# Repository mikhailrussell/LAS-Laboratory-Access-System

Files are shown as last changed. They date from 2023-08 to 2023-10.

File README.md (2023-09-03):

# LAS-Laboratory-Access-System-
Current PCB Version: **LAS_V2**
You can find the most recent version of the PCB under /PCB

# User Requirements
|Number/Label	|Requirement|
|---|---|
|UR-1	| Allow clients to book particular sessions (time and date). |
|UR-2|	Allow clients to view what the status of laboratory.
|UR-3|	Integrate access control with the current student card for identification.
|UR-4|	Provide access to clients who have been allocated the correct session.
|UR-5|	The status of benches must be physically displayed on the bench.
|UR-6|	The system must be easily scalable.
|UR-7|	The system must be cheap.

# Hardware Functional Requirements

|Number/label	|Requirements	|Acceptance Test Criteria|
|---|---|---|
|FR-1	|Retrieve student's IDs from 125KHz RFID student cards.	|
|FR-2	|Connect to network wirelessly.	|
|FR-3	|Each bench must have LEDs to indicate whether the bench is available, booked or in use.|	
|FR-4	|Each node must be able to activate a 220V relay.	|
|FR-5	|Operate off 12V	|
|FR-6	|Cheap and easily scalable	|

# Software Functional Requirements

|Number/label	|Requirements	|Acceptance Test Criteria|
|---|---|---|
|FR-6|	Site accessible via Wi-Fi (website accessible)	|
FR-7|	Free	|
FR-8|	Client able to book time and date	|
FR-9	|Current lab status is displayed (eg. Current tables free)	|

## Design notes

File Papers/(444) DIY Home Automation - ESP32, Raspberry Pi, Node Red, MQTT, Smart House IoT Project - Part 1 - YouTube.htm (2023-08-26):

•

NaN / NaN

Back

(https://www.youtube.com/) ZA

Skip navigation

Search

Search

Search with your voice

9+

Notifications

Avatar image

(https://www.youtube.com/) ZA

DIY Home Automation - ESP32, Raspberry Pi, Node Red, MQTT, Smart House || IoT Project - Part 1

Watch later

Share

Copy link

Info

Shopping

Tap to unmute

If playback doesn't begin shortly, try restarting your device.

5 seconds

More from Boris Dusnoki

Up next

Live

Upcoming

CancelPlay Now

Boris Dusnoki (https://www.youtube.com/channel/UCgOEgQpu1thY7D-GzO5vdeQ)

Subscribe

Subscribed

Web developer, electronics hobbyist, guitar enthusiast and traveler.

DIY Arduino Ambilight RGB WS2812b Full Build & How-To (https://www.youtube.com/watch?v=juC-3imLoTQ)

8:15

You're signed out

Videos you watch may be added to the TV's watch history and influence TV recommendations. To avoid this, cancel and sign in to YouTube on your computer.

CancelConfirm

Switch camera

Share

Include playlist

An error occurred while retrieving sharing information. Please try again later.

7:16

(https://www.youtube.com/watch?v=_DO2wHI6JWQ)

7:47 / 12:24•Watch full videoLive

•

•

Scroll for details

# DIY Home Automation - ESP32, Raspberry Pi, Node Red, MQTT, Smart House || IoT Project - Part 1

 (https://www.youtube.com/@dusnoki)

Boris Dusnoki (https://www.youtube.com/@dusnoki)

Boris Dusnoki

4.06K subscribers

Subscribe

<__slot-el>

Subscribed

1.3K

I like this

I dislike this

Share

Share

Download

Download

Clip

Clip

Save

Save

61K views 4 years ago Raspberry Pi (https://www.youtube.com/playlist?list=PLuWKCYWPj895uvLiwB4n7BlYf247BNhpS)

Show less

JLCPCB Prototype for $2(Any Color): https://jlcpcb.com (https://www.youtube.com/redirect?event=video_description&q=https%3A%2F%2Fjlcpcb.com%2F&v=kRvNlSJs0Hg) !!!! IMPORTANT !!!! Please use version 1.0.0 of the ESP32 board from the board manager. …...more

...more

Show less

61,500 views • Nov 28, 2018 • Raspberry Pi

Raspberry Pi (https://www.youtube.com/playlist?list=PLuWKCYWPj895uvLiwB4n7BlYf247BNhpS)

# DIY Home Automation - ESP32, Raspberry Pi, Node Red, MQTT, Smart House || IoT Project - Part 1

61,500 views61K views

Nov 28, 2018

1.3K

I like this

I dislike this

Share

Share

Download

Download

Clip

Clip

Save

Save

(https://www.youtube.com/@dusnoki)

Boris Dusnoki (https://www.youtube.com/@dusnoki)

Boris Dusnoki

4.06K subscribers

Subscribe

<__slot-el>

Subscribed

JLCPCB Prototype for $2(Any Color): https://jlcpcb.com (https://www.youtube.com/redirect?event=video_description&q=https%3A%2F%2Fjlcpcb.com%2F&v=kRvNlSJs0Hg) !!!! IMPORTANT !!!! Please use version 1.0.0 of the ESP32 board from the board manager. Check out my first attempt at a DIY Home Automation project. With this small box I could control my tv, led strip, sound system and lights. It would also monitor the inside humidity and temperature as well as get real time data from an external API for the outside humidity and temperature and display them nicely in a graph. I even save all these values to a local database and display those values in a chart based on the date I choose. Part 2: Code and Node Red Explanation - • DIY Home Automati... (https://www.youtube.com/watch?v=menuVmKz-mc&t=0s) ESP32: http://y.sudokin.com/esp32 (https://www.youtube.com/redirect?event=video_description&q=http%3A%2F%2Fy.sudokin.com%2Fesp32&v=kRvNlSJs0Hg) - AliExpress http://y.sudokin.com/besp32 (https://www.youtube.com/redirect?event=video_description&q=http%3A%2F%2Fy.sudokin.com%2Fbesp32&v=kRvNlSJs0Hg) - Banggood http://y.sudokin.com/auesp32 (https://www.youtube.com/redirect?event=video_description&q=http%3A%2F%2Fy.sudokin.com%2Fauesp32&v=kRvNlSJs0Hg) - Amazon US http://y.sudokin.com/akesp32 (https://www.youtube.com/redirect?event=video_description&q=http%3A%2F%2Fy.sudokin.com%2Fakesp32&v=kRvNlSJs0Hg) - Amazon UK http://y.sudokin.com/adesp32 (https://www.youtube.com/redirect?event=video_description&q=http%3A%2F%2Fy.sudokin.com%2Fadesp32&v=kRvNlSJs0Hg) - Amazon DE Raspberry Pi Zero W: http://y.sudokin.com/rpzw (https://www.youtube.com/redirect?event=video_description&q=http%3A%2F%2Fy.sudokin.com%2Frpzw&v=kRvNlSJs0Hg) - AliExpress http://y.sudokin.com/brpzw (https://www.youtube.com/redirect?event=video_description&q=http%3A%2F%2Fy.sudokin.com%2Fbrpzw&v=kRvNlSJs0Hg) - Banggood http://y.sudokin.com/aurpzw (https://www.youtube.com/redirect?event=video_description&q=http%3A%2F%2Fy.sudokin.com%2Faurpzw&v=kRvNlSJs0Hg) - Amazon US http://y.sudokin.com/akrpzw (https://www.youtube.com/redirect?event=video_description&q=http%3A%2F%2Fy.sudokin.com%2Fakrpzw&v=kRvNlSJs0Hg) - Amazon UK http://y.sudokin.com/adrpzw (https://www.youtube.com/redirect?event=video_description&q=http%3A%2F%2Fy.sudokin.com%2Fadrpzw&v=kRvNlSJs0Hg) - Amazon DE HTU21D Temperature and Humidity Sensor: http://y.sudokin.com/htu21d (https://www.youtube.com/redirect?event=video_description&q=http%3A%2F%2Fy.sudokin.com%2Fhtu21d&v=kRvNlSJs0Hg) - AliExpress http://y.sudokin.com/bhtu21d (https://www.youtube.com/redirect?event=video_description&q=http%3A%2F%2Fy.sudokin.com%2Fbhtu21d&v=kRvNlSJs0Hg) - Banggood http://y.sudokin.com/auhtu21d (https://www.youtube.com/redirect?event=video_description&q=http%3A%2F%2Fy.sudokin.com%2Fauhtu21d&v=kRvNlSJs0Hg) - Amazon US http://y.sudokin.com/akhtu21d (https://www.youtube.com/redirect?event=video_description&q=http%3A%2F%2Fy.sudokin.com%2Fakhtu21d&v=kRvNlSJs0Hg) - Amazon UK http://y.sudokin.com/adhtu21d (https://www.youtube.com/redirect?event=video_description&q=http%3A%2F%2Fy.sudokin.com%2Fadhtu21d&v=kRvNlSJs0Hg) - Amazon DE 1838 IR Receiver: http://y.sudokin.com/1838 (https://www.youtube.com/redirect?event=video_description&q=http%3A%2F%2Fy.sudokin.com%2F1838&v=kRvNlSJs0Hg) - AliExpress http://y.sudokin.com/b1838 (https://www.youtube.com/redirect?event=video_description&q=http%3A%2F%2Fy.sudokin.com%2Fb1838&v=kRvNlSJs0Hg) - Banggood http://y.sudokin.com/au1838 (https://www.youtube.com/redirect?event=video_description&q=http%3A%2F%2Fy.sudokin.com%2Fau1838&v=kRvNlSJs0Hg) - Amazon US http://y.sudokin.com/ak1838 (https://www.youtube.com/redirect?event=video_description&q=http%3A%2F%2Fy.sudokin.com%2Fak1838&v=kRvNlSJs0Hg) - Amazon UK http://y.sudokin.com/ad1838 (https://www.youtube.com/redirect?event=video_description&q=http%3A%2F%2Fy.sudokin.com%2Fad1838&v=kRvNlSJs0Hg) - Amazon DE Female Pin Headers: http://y.sudokin.com/ph (https://www.youtube.com/redirect?event=video_description&q=http%3A%2F%2Fy.sudokin.com%2Fph&v=kRvNlSJs0Hg) - Aliexpress http://y.sudokin.com/auph (https://www.youtube.com/redirect?event=video_description&q=http%3A%2F%2Fy.sudokin.com%2Fauph&v=kRvNlSJs0Hg) - Amazon US http://y.sudokin.com/akph (https://www.youtube.com/redirect?event=video_description&q=http%3A%2F%2Fy.sudokin.com%2Fakph&v=kRvNlSJs0Hg) - Amazon UK http://y.sudokin.com/adph (https://www.youtube.com/redirect?event=video_description&q=http%3A%2F%2Fy.sudokin.com%2Fadph&v=kRvNlSJs0Hg) - Amazon DE Soldering station: http://y.sudokin.com/auss (https://www.youtube.com/redirect?event=video_description&q=http%3A%2F%2Fy.sudokin.com%2Fauss&v=kRvNlSJs0Hg) - Amazon US http://y.sudokin.com/akss (https://www.youtube.com/redirect?event=video_description&q=http%3A%2F%2Fy.sudokin.com%2Fakss&v=kRvNlSJs0Hg) - Amazon UK http://y.sudokin.com/adss (https://www.youtube.com/redirect?event=video_description&q=http%3A%2F%2Fy.sudokin.com%2Fadss&v=kRvNlSJs0Hg) - Amazon DE Software Links: Raspberry Pi Image - http://y.sudokin.com/dietpi (https://www.youtube.com/redirect?event=video_description&q=http%3A%2F%2Fy.sudokin.com%2Fdietpi&v=kRvNlSJs0Hg) EasyEDA Project - http://y.sudokin.com/hauea (https://www.youtube.com/redirect?event=video_description&q=http%3A%2F%2Fy.sudokin.com%2Fhauea&v=kRvNlSJs0Hg) Gerber Files - http://y.sudokin.com/hauger (https://www.youtube.com/redirect?event=video_description&q=http%3A%2F%2Fy.sudokin.com%2Fhauger&v=kRvNlSJs0Hg) Github Project Repository - http://y.sudokin.com/haugh (https://www.youtube.com/redirect?event=video_description&q=http%3A%2F%2Fy.sudokin.com%2Fhaugh&v=kRvNlSJs0Hg) Arduino ESP32 Github Repository - http://y.sudokin.com/aresp32gh (https://www.youtube.com/redirect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) Arduino IDE - https://www.arduino.cc/en/Main/Software (https://www.youtube.com/redirect?event=video_description&v=kRvNlSJs0Hg) Etcher - https://www.balena.io/etcher/ (https://www.youtube.com/redirect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) Node Red Admin address: ip-address-to-raspberry-pi:1880 username: admin password: password Node Red UI address: ip-address-to-raspberry-pi:1880/ui username: user password: password Raspberry pi user: pi Raspberry pi password: password →Support the channel via Patreon, Paypal, Bitcoin, Etherium or by visiting affiliate links https://sudokin.com/donate (https://www.youtube.com/redirect?event=video_description&q=https%3A%2F%2Fsudokin.com%2Fdonate&v=kRvNlSJs0Hg) Follow me on LBRY: https://y.sudokin.com/lbry (https://www.youtube.com/redirect?event=video_description&q=https%3A%2F%2Fy.sudokin.com%2Flbry&v=kRvNlSJs0Hg) Follow me on Twitter & Instagram and my blog: https://twitter.com/dusnoki (https://www.youtube.com/redirect?event=video_description&q=https%3A%2F%2Ftwitter.com%2Fdusnoki&v=kRvNlSJs0Hg) https://instagram.com/dusnoki (https://www.youtube.com/redirect?event=video_description&q=https%3A%2F%2Finstagram.com%2Fdusnoki&v=kRvNlSJs0Hg) https://sudokin.com (https://www.youtube.com/redirect?event=video_description&q=https%3A%2F%2Fsudokin.com%2F&v=kRvNlSJs0Hg) Or hop on to my Discord channel: https://discord.gg/Aef4VRc (https://www.youtube.com/redirect?event=video_description&q=https%3A%2F%2Fdiscord.gg%2FAef4VRc&v=kRvNlSJs0Hg) Thanks for watching, and I hope you learned something ;)

## Key moments

## View all

#### communicate using the mqtt protocol (https://www.youtube.com/watch?v=kRvNlSJs0Hg&t=80s)

#### communicate using the mqtt protocol

1:20

1:20

#### send infrared controls to multiple devices (https://www.youtube.com/watch?v=kRvNlSJs0Hg&t=333s)

#### send infrared controls to multiple devices

5:33

5:33

#### insert your sd card-raspberry pi (https://www.youtube.com/watch?v=kRvNlSJs0Hg&t=437s)

#### insert your sd card-raspberry pi

7:17

7:17

#### use the arduino ide for uploading (https://www.youtube.com/watch?v=kRvNlSJs0Hg&t=450s)

#### use the arduino ide for uploading

7:30

7:30

#### put all the necessary components of the breadboard (https://www.youtube.com/watch?v=kRvNlSJs0Hg&t=528s)

#### put all the necessary components of the breadboard

8:48

8:48

#### create a custom pcb for this project (https://www.youtube.com/watch?v=kRvNlSJs0Hg&t=542s)

#### create a custom pcb for this project

9:02

9:02

#### solder the esp 32 to the board (https://www.youtube.com/watch?v=kRvNlSJs0Hg&t=625s)

#### solder the esp 32 to the board

10:25

10:25

#### solder each wire in place to the board (https://www.youtube.com/watch?v=kRvNlSJs0Hg&t=655s)

#### solder each wire in place to the board

10:55

10:55

### Featured playlist

5 videos (https://www.youtube.com/playlist?list=PLuWKCYWPj895uvLiwB4n7BlYf247BNhpS)

Raspberry Pi

Boris Dusnoki

### Boris Dusnoki (https://www.youtube.com/@dusnoki)

4.06K subscribers

Videos (https://www.youtube.com/channel/UCgOEgQpu1thY7D-GzO5vdeQ/videos)

About (https://www.youtube.com/channel/UCgOEgQpu1thY7D-GzO5vdeQ/about)

39:33 (https://www.youtube.com/watch?v=menuVmKz-mc)

DIY Home Automation - Part 2 Code and Node Red Explanation | ESP32, Raspberry Pi, MQTT, Smart House (https://www.youtube.com/watch?v=menuVmKz-mc)

by Boris Dusnoki

10K views · 4 years ago

Show less ...more

## Key moments

#### communicate using the mqtt protocol (https://www.youtube.com/watch?v=kRvNlSJs0Hg&t=80s)

#### communicate using the mqtt protocol

1:20

1:20

#### send infrared controls to multiple devices (https://www.youtube.com/watch?v=kRvNlSJs0Hg&t=333s)

#### send infrared controls to multiple devices

5:33

5:33

#### insert your sd card-raspberry pi (https://www.youtube.com/watch?v=kRvNlSJs0Hg&t=437s)

#### insert your sd card-raspberry pi

7:17

7:17

#### use the arduino ide for uploading (https://www.youtube.com/watch?v=kRvNlSJs0Hg&t=450s)

#### use the arduino ide for uploading

7:30

7:30

#### put all the necessary components of the breadboard (https://www.youtube.com/watch?v=kRvNlSJs0Hg&t=528s)

#### put all the necessary components of the breadboard

8:48

8:48

#### create a custom pcb for this project (https://www.youtube.com/watch?v=kRvNlSJs0Hg&t=542s)

#### create a custom pcb for this project

9:02

9:02

#### solder the esp 32 to the board (https://www.youtube.com/watch?v=kRvNlSJs0Hg&t=625s)

#### solder the esp 32 to the board

10:25

10:25

#### solder each wire in place to the board (https://www.youtube.com/watch?v=kRvNlSJs0Hg&t=655s)

#### solder each wire in place to the board

10:55

10:55

#### added some heat shrink tubing to the wires of the infrared led (https://www.youtube.com/watch?v=kRvNlSJs0Hg&t=665s)

#### added some heat shrink tubing to the wires of the infrared led

11:05

11:05

Sync to video time

Sync to video time

## Create clip

Mikhail Russell

Public

Add a title (required)

0/140

–

30.0 seconds

Cancel

Share clip

Continue clipping after ad finishes

Can’t create clip while ad is playing

## Description

DIY Home Automation - ESP32, Raspberry Pi, Node Red, MQTT, Smart House || IoT Project - Part 1

(https://www.youtube.com/@dusnoki)

Boris Dusnoki

Boris Dusnoki

1.3K Likes

61,500 Views

2018 Nov 28

JLCPCB Prototype for $2(Any Color): https://jlcpcb.com (https://www.youtube.com/redirect?event=video_description&q=https%3A%2F%2Fjlcpcb.com%2F&v=kRvNlSJs0Hg) !!!! IMPORTANT !!!! Please use version 1.0.0 of the ESP32 board from the board manager. Check out my first attempt at a DIY Home Automation project. With this small box I could control my tv, led strip, sound system and lights. It would also monitor the inside humidity and temperature as well as get real time data from an external API for the outside humidity and temperature and display them nicely in a graph. I even save all these values to a local database and display those values in a chart based on the date I choose. Part 2: Code and Node Red Explanation - • DIY Home Automati... (https://www.youtube.com/watch?v=menuVmKz-mc&t=0s) ESP32: http://y.sudokin.com/esp32 (https://www.youtube.com/redirect?event=video_description&q=http%3A%2F%2Fy.sudokin.com%2Fesp32&v=kRvNlSJs0Hg) - AliExpress http://y.sudokin.com/besp32 (https://www.youtube.com/redirect?event=video_description&q=http%3A%2F%2Fy.sudokin.com%2Fbesp32&v=kRvNlSJs0Hg) - Banggood http://y.sudokin.com/auesp32 (https://www.youtube.com/redirect?event=video_description&q=http%3A%2F%2Fy.sudokin.com%2Fauesp32&v=kRvNlSJs0Hg) - Amazon US http://y.sudokin.com/akesp32 (https://www.youtube.com/redirect?event=video_description&q=http%3A%2F%2Fy.sudokin.com%2Fakesp32&v=kRvNlSJs0Hg) - Amazon UK http://y.sudokin.com/adesp32 (https://www.youtube.com/redirect?event=video_description&q=http%3A%2F%2Fy.sudokin.com%2Fadesp32&v=kRvNlSJs0Hg) - Amazon DE Raspberry Pi Zero W: http://y.sudokin.com/rpzw (https://www.youtube.com/redirect?event=video_description&q=http%3A%2F%2Fy.sudokin.com%2Frpzw&v=kRvNlSJs0Hg) - AliExpress http://y.sudokin.com/brpzw (https://www.youtube.com/redirect?event=video_description&q=http%3A%2F%2Fy.sudokin.com%2Fbrpzw&v=kRvNlSJs0Hg) - Banggood http://y.sudokin.com/aurpzw (https://www.youtube.com/redirect?event=video_description&q=http%3A%2F%2Fy.sudokin.com%2Faurpzw&v=kRvNlSJs0Hg) - Amazon US http://y.sudokin.com/akrpzw (https://www.youtube.com/redirect?event=video_description&q=http%3A%2F%2Fy.sudokin.com%2Fakrpzw&v=kRvNlSJs0Hg) - Amazon UK http://y.sudokin.com/adrpzw (https://www.youtube.com/redirect?event=video_description&q=http%3A%2F%2Fy.sudokin.com%2Fadrpzw&v=kRvNlSJs0Hg) - Amazon DE HTU21D Temperature and Humidity Sensor: http://y.sudokin.com/htu21d (https://www.youtube.com/redirect?event=video_description&q=http%3A%2F%2Fy.sudokin.com%2Fhtu21d&v=kRvNlSJs0Hg) - AliExpress http://y.sudokin.com/bhtu21d (https://www.youtube.com/redirect?event=video_description&q=http%3A%2F%2Fy.sudokin.com%2Fbhtu21d&v=kRvNlSJs0Hg) - Banggood http://y.sudokin.com/auhtu21d (https://www.youtube.com/redirect?event=video_description&q=http%3A%2F%2Fy.sudokin.com%2Fauhtu21d&v=kRvNlSJs0Hg) - Amazon US http://y.sudokin.com/akhtu21d (https://www.youtube.com/redirect?event=video_description&q=http%3A%2F%2Fy.sudokin.com%2Fakhtu21d&v=kRvNlSJs0Hg) - Amazon UK http://y.sudokin.com/adhtu21d (https://www.youtube.com/redirect?event=video_description&q=http%3A%2F%2Fy.sudokin.com%2Fadhtu21d&v=kRvNlSJs0Hg) - Amazon DE 1838 IR Receiver: http://y.sudokin.com/1838 (https://www.youtube.com/redirect?event=video_description&q=http%3A%2F%2Fy.sudokin.com%2F1838&v=kRvNlSJs0Hg) - AliExpress http://y.sudokin.com/b1838 (https://www.youtube.com/redirect?event=video_description&q=http%3A%2F%2Fy.sudokin.com%2Fb1838&v=kRvNlSJs0Hg) - Banggood http://y.sudokin.com/au1838 (https://www.youtube.com/redirect?event=video_description&q=http%3A%2F%2Fy.sudokin.com%2Fau1838&v=kRvNlSJs0Hg) - Amazon US http://y.sudokin.com/ak1838 (https://www.youtube.com/redirect?event=video_description&q=http%3A%2F%2Fy.sudokin.com%2Fak1838&v=kRvNlSJs0Hg) - Amazon UK http://y.sudokin.com/ad1838 (https://www.youtube.com/redirect?event=video_description&q=http%3A%2F%2Fy.sudokin.com%2Fad1838&v=kRvNlSJs0Hg) - Amazon DE Female Pin Headers: http://y.sudokin.com/ph (https://www.youtube.com/redirect?event=video_description&q=http%3A%2F%2Fy.sudokin.com%2Fph&v=kRvNlSJs0Hg) - Aliexpress http://y.sudokin.com/auph (https://www.youtube.com/redirect?event=video_description&q=http%3A%2F%2Fy.sudokin.com%2Fauph&v=kRvNlSJs0Hg) - Amazon US http://y.sudokin.com/akph (https://www.youtube.com/redirect?event=video_description&q=http%3A%2F%2Fy.sudokin.com%2Fakph&v=kRvNlSJs0Hg) - Amazon UK http://y.sudokin.com/adph (https://www.youtube.com/redirect?event=video_description&q=http%3A%2F%2Fy.sudokin.com%2Fadph&v=kRvNlSJs0Hg) - Amazon DE Soldering station: http://y.sudokin.com/auss (https://www.youtube.com/redirect?event=video_description&q=http%3A%2F%2Fy.sudokin.com%2Fauss&v=kRvNlSJs0Hg) - Amazon US http://y.sudokin.com/akss (https://www.youtube.com/redirect?event=video_description&q=http%3A%2F%2Fy.sudokin.com%2Fakss&v=kRvNlSJs0Hg) - Amazon UK http://y.sudokin.com/adss (https://www.youtube.com/redirect?event=video_description&q=http%3A%2F%2Fy.sudokin.com%2Fadss&v=kRvNlSJs0Hg) - Amazon DE Software Links: Raspberry Pi Image - http://y.sudokin.com/dietpi (https://www.youtube.com/redirect?event=video_description&q=http%3A%2F%2Fy.sudokin.com%2Fdietpi&v=kRvNlSJs0Hg) EasyEDA Project - http://y.sudokin.com/hauea (https://www.youtube.com/redirect?event=video_description&q=http%3A%2F%2Fy.sudokin.com%2Fhauea&v=kRvNlSJs0Hg) Gerber Files - http://y.sudokin.com/hauger (https://www.youtube.com/redirect?event=video_description&q=http%3A%2F%2Fy.sudokin.com%2Fhauger&v=kRvNlSJs0Hg) Github Project Repository - http://y.sudokin.com/haugh (https://www.youtube.com/redirect?event=video_description&q=http%3A%2F%2Fy.sudokin.com%2Fhaugh&v=kRvNlSJs0Hg) Arduino ESP32 Github Repository - http://y.sudokin.com/aresp32gh (https://www.youtube.com/redirect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) Arduino IDE - https://www.arduino.cc/en/Main/Software (https://www.youtube.com/redirect?event=video_description&v=kRvNlSJs0Hg) Etcher - https://www.balena.io/etcher/ (https://www.youtube.com/redirect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) Node Red Admin address: ip-address-to-raspberry-pi:1880 username: admin password: password Node Red UI address: ip-address-to-raspberry-pi:1880/ui username: user password: password Raspberry pi user: pi Raspberry pi password: password →Support the channel via Patreon, Paypal, Bitcoin, Etherium or by visiting affiliate links https://sudokin.com/donate (https://www.youtube.com/redirect?event=video_description&q=https%3A%2F%2Fsudokin.com%2Fdonate&v=kRvNlSJs0Hg) Follow me on LBRY: https://y.sudokin.com/lbry (https://www.youtube.com/redirect?event=video_description&q=https%3A%2F%2Fy.sudokin.com%2Flbry&v=kRvNlSJs0Hg) Follow me on Twitter & Instagram and my blog: https://twitter.com/dusnoki (https://www.youtube.com/redirect?event=video_description&q=https%3A%2F%2Ftwitter.com%2Fdusnoki&v=kRvNlSJs0Hg) https://instagram.com/dusnoki (https://www.youtube.com/redirect?event=video_description&q=https%3A%2F%2Finstagram.com%2Fdusnoki&v=kRvNlSJs0Hg) https://sudokin.com (https://www.youtube.com/redirect?event=video_description&q=https%3A%2F%2Fsudokin.com%2F&v=kRvNlSJs0Hg) Or hop on to my Discord channel: https://discord.gg/Aef4VRc (https://www.youtube.com/redirect?event=video_description&q=https%3A%2F%2Fdiscord.gg%2FAef4VRc&v=kRvNlSJs0Hg) Thanks for watching, and I hope you learned something ;)

Show less Show more

## Key moments

## View all

#### communicate using the mqtt protocol (https://www.youtube.com/watch?v=kRvNlSJs0Hg&t=80s)

#### communicate using the mqtt protocol

1:20

1:20

#### send infrared controls to multiple devices (https://www.youtube.com/watch?v=kRvNlSJs0Hg&t=333s)

#### send infrared controls to multiple devices

5:33

5:33

#### insert your sd card-raspberry pi (https://www.youtube.com/watch?v=kRvNlSJs0Hg&t=437s)

#### insert your sd card-raspberry pi

7:17

7:17

#### use the arduino ide for uploading (https://www.youtube.com/watch?v=kRvNlSJs0Hg&t=450s)

#### use the arduino ide for uploading

7:30

7:30

### Featured playlist

5 videos (https://www.youtube.com/playlist?list=PLuWKCYWPj895uvLiwB4n7BlYf247BNhpS)

Raspberry Pi

Boris Dusnoki

### Boris Dusnoki (https://www.youtube.com/@dusnoki)

4.06K subscribers

Videos (https://www.youtube.com/channel/UCgOEgQpu1thY7D-GzO5vdeQ/videos)

About (https://www.youtube.com/channel/UCgOEgQpu1thY7D-GzO5vdeQ/about)

39:33 (https://www.youtube.com/watch?v=menuVmKz-mc)

DIY Home Automation - Part 2 Code and Node Red Explanation | ESP32, Raspberry Pi, MQTT, Smart House (https://www.youtube.com/watch?v=menuVmKz-mc)

by Boris Dusnoki

10K views · 4 years ago

## Comments 77

Top comments

Newest first

## Transcript

NaN / NaN

All From Boris Dusnoki Single-board computers Breadboards Related For you Recently uploaded

 (https://www.youtube.com/watch?v=-1PRT-nGI4M)

23:25 Now playing

### Armored Core VI Fires of Rubicon is a slow burn (Hands-on impressions) (https://www.youtube.com/watch?v=-1PRT-nGI4M)

Skill Up

Skill Up

Verified

•

•

32K views 1 hour ago

New

 (https://www.youtube.com/watch?v=_DO2wHI6JWQ)

12:32 Now playing

### Raspberry Pi IoT Server Tutorial: InfluxDB, MQTT, Grafana, Node-RED & Docker (https://www.youtube.com/watch?v=_DO2wHI6JWQ)

Learn Embedded Systems

Learn Embedded Systems

•

•

125K views 8 months ago

 (https://www.youtube.com/watch?v=Q0S0xOW35k8)

28:06 Now playing

### MQTT 101: Integrate your DIY Devices into Home Assistant (https://www.youtube.com/watch?v=Q0S0xOW35k8)

ResinChem Tech

ResinChem Tech

•

•

24K views 5 months ago

 (https://www.youtube.com/watch?v=juCbVRq4Xhg)

9:41 Now playing

### 12 Useful & Interesting ESP32 Projects for Beginners! (https://www.youtube.com/watch?v=juCbVRq4Xhg)

ToP Projects Compilation

ToP Projects Compilation

•

•

433K views 11 months ago

 (https://www.youtube.com/watch?v=menuVmKz-mc)

39:33 Now playing

### DIY Home Automation - Part 2 Code and Node Red Explanation | ESP32, Raspberry Pi, MQTT, Smart House (https://www.youtube.com/watch?v=menuVmKz-mc)

Boris Dusnoki

Boris Dusnoki

•

•

10K views 4 years ago

 (https://www.youtube.com/watch?v=hiVcgUdjy0A)

1:38:50 Now playing

### Node-Red Automation, MQTT, NodeMCU & MicroPython (https://www.youtube.com/watch?v=hiVcgUdjy0A)

Kevin McAleer

Kevin McAleer

•

•

26K views Streamed 2 years ago

 (https://www.youtube.com/watch?v=ebsXSCKsHeQ)

6:22 Now playing

### How to setup MQTT for Raspberry Pi and ESP32 for IOT and Robotics projects (https://www.youtube.com/watch?v=ebsXSCKsHeQ)

Jitesh helloworld

Jitesh helloworld

•

•

10K views 1 year ago

 (https://www.youtube.com/watch?v=F0o1C7nEgw0)

10:18 Now playing

### The Raspberry Pi Pico WAS Overrated! But that changed! (https://www.youtube.com/watch?v=F0o1C7nEgw0)

GreatScott!

GreatScott!

Verified

•

•

481K views 1 year ago

 (https://www.youtube.com/watch?v=h18LMskRNMA)

30:50 Now playing

### Add a web control panel to your project - the web server (https://www.youtube.com/watch?v=h18LMskRNMA)

Bytes N Bits

Bytes N Bits

•

•

3.2K views 3 months ago

 (https://www.youtube.com/watch?v=L8wVSx3VIR8)

24:03 Now playing

### TWITTER IS ACTUALLY DEAD (https://www.youtube.com/watch?v=L8wVSx3VIR8)

HasanAbi

HasanAbi

Verified

•

•

4.6K views 10 minutes ago

New

27:10 Now playing (https://www.youtube.com/watch?v=KXcwUdDqXXo)

### Beginners Guide to Node-RED in Home Assistant (https://www.youtube.com/watch?v=KXcwUdDqXXo)

Let's Automate

Let's Automate

•

•

16K views 4 months ago

10:58 Now playing (https://www.youtube.com/watch?v=x5A5S0hoyJ0)

### Simple ESP32 IoT Sensor Node Tutorial: WiFi Enabled MQTT Sensor Data Node (https://www.youtube.com/watch?v=x5A5S0hoyJ0)

Learn Embedded Systems

Learn Embedded Systems

•

•

21K views 7 months ago

19:34 Now playing (https://www.youtube.com/watch?v=p3vJxGKWDIg)

### MQTT with a Raspberry Pi and an Arduino (https://www.youtube.com/watch?v=p3vJxGKWDIg)

Gary Explains

Gary Explains

•

•

63K views 3 years ago

9 videos Now playing (https://www.youtube.com/watch?v=xPlN_Tk3VLQ&list=PLWNDWPAClRVqNUIuJylljkQfFSeIpuxUi&pp=iAQB)

### ESP-32 - Advanced microcontroller with WiFi & Bluetooth (https://www.youtube.com/watch?v=xPlN_Tk3VLQ&list=PLWNDWPAClRVqNUIuJylljkQfFSeIpuxUi&pp=iAQB)

DroneBot Workshop

DroneBot Workshop

Verified

•

•

10:02 Now playing (https://www.youtube.com/watch?v=nzDnr76fZCc)

### Cheap DIY Arduino Ambilight 2.0 (Revisited) RGB WS2812b LED Full Build & How-To (https://www.youtube.com/watch?v=nzDnr76fZCc)

Boris Dusnoki

Boris Dusnoki

•

•

227K views 3 years ago

24:55 Now playing (https://www.youtube.com/watch?v=k_PJLkfqDuI)

### How YOU can Get Started with The ESP32-CAM for DIY Security Cameras (https://www.youtube.com/watch?v=k_PJLkfqDuI)

Max Imagination

Max Imagination

•

•

72K views 4 months ago

17:28 Now playing (https://www.youtube.com/watch?v=0K9q4IuB_oA)

### MQTT Broker/Bridge on the ESP8266 (https://www.youtube.com/watch?v=0K9q4IuB_oA)

Martin Ger

Martin Ger

•

•

79K views 5 years ago

13:22 Now playing (https://www.youtube.com/watch?v=gnE4v-PcYKQ)

### #369 Definitive Guide to Attaching Sensors to the Raspberry Pi (Tutorial) (https://www.youtube.com/watch?v=gnE4v-PcYKQ)

Andreas Spiess

Andreas Spiess

Verified

•

•

82K views 2 years ago

15:23 Now playing (https://www.youtube.com/watch?v=P8DnANWusrM)

### Monitor Room Temperature Remotely with Arduino & MQTT (https://www.youtube.com/watch?v=P8DnANWusrM)

Gary Explains

Gary Explains

•

•

12K views 9 months ago

33:05 Now playing (https://www.youtube.com/watch?v=Y38qRYYAwAI)

### Home Assistant Setup Made Easy: The Ultimate Guide (https://www.youtube.com/watch?v=Y38qRYYAwAI)

Crosstalk Solutions

Crosstalk Solutions

Verified

•

•

131K views 3 months ago

Show more

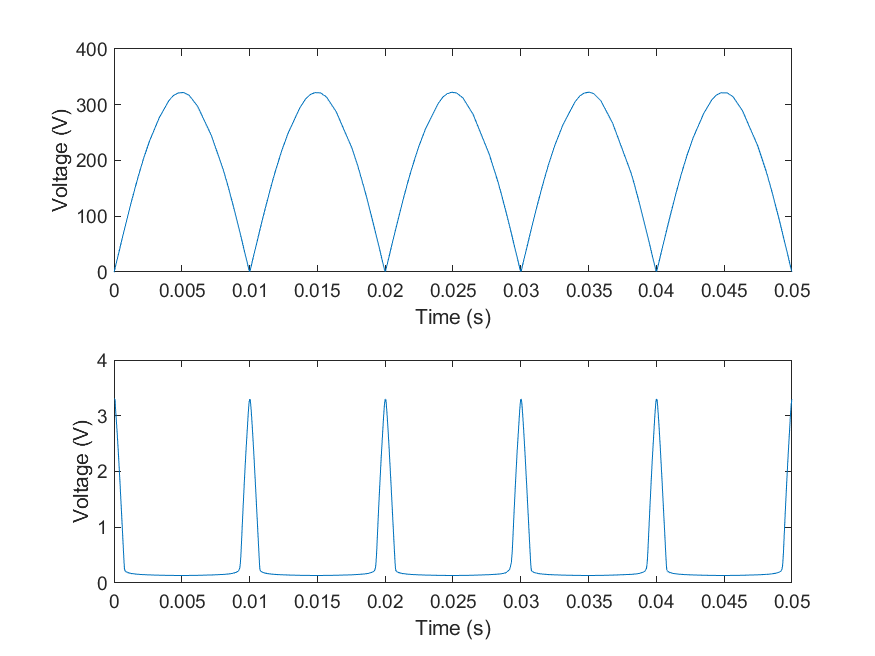
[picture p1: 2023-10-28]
sim/opto_output_and_input.png

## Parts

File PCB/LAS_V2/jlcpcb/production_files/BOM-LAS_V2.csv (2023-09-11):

Comment | Designator | Footprint | LCSC
0.1uF | C2,C4,C5 | C_0603_1608Metric | C14663
1uF | C1,C7,C9 | C_0603_1608Metric | C15849
10k | R13,R14,R2,R26,R27,R28,R29 | R_1206_3216Metric | C17902
1N5819WS | D7 | D_SOD-323 | C191023
10uF | C3,C6 | C_0603_1608Metric | C19702
AO3400A | Q5,Q6 | SOT-23 | C20917
1k | R21,R4,R5,R6,R7,R8 | R_0603_1608Metric | C21190
150 | R9 | R_0603_1608Metric | C22808
LED | D6 | LED_0603_1608Metric | C2286
YELLOW LED | D3 | LED_0805_2012Metric | C2296
GREEN LED | D5 | LED_0805_2012Metric | C2297
5.1k | R10,R11 | R_0603_1608Metric | C23186
MB10S | D8 | MBS_L4.7-W3.8-P2.40-LS7.0-TL | C2488
10k (1%) | R12 | R_0603_1608Metric | C25804
WS2812B | D4,D9 | LED_WS2812B_PLCC4_5.0x5.0mm_P3.2mm | C2843785
ESP32-S3-WROOM-1 | U1 | ESP32-S3-WROOM-1 | C2913200
USB_C_Receptacle_USB2.0 | J7 | USB-C_SMD-TYPE-C-31-M-12 | C2927038
EL357N | U5 | SOP-4_3.8x4.1mm_P2.54mm | C29981
SRD-05VDC-SL-C | K1 | Relay_SPDT_SANYOU_SRD_Series_Form_C | C35449
2.2k | R20,R24 | R_0603_1608Metric | C4190
AMS1117-3.3 | U2 | SOT-223-3_TabPin2 | C6186
47k 3W | R17 | R_Axial_DIN0617_L17.0mm_D6.0mm_P20.32mm_Horizontal | C714661
ZMMxx | D11 | D_MiniMELF | C8062
RED LED | D1,D2 | LED_0805_2012Metric | C84256
CH340C | U3 | SOIC-16_3.9x9.9mm_P1.27mm | C84681
MMBT2222A | Q1,Q2,Q3,Q4 | SOT-23 | C8512

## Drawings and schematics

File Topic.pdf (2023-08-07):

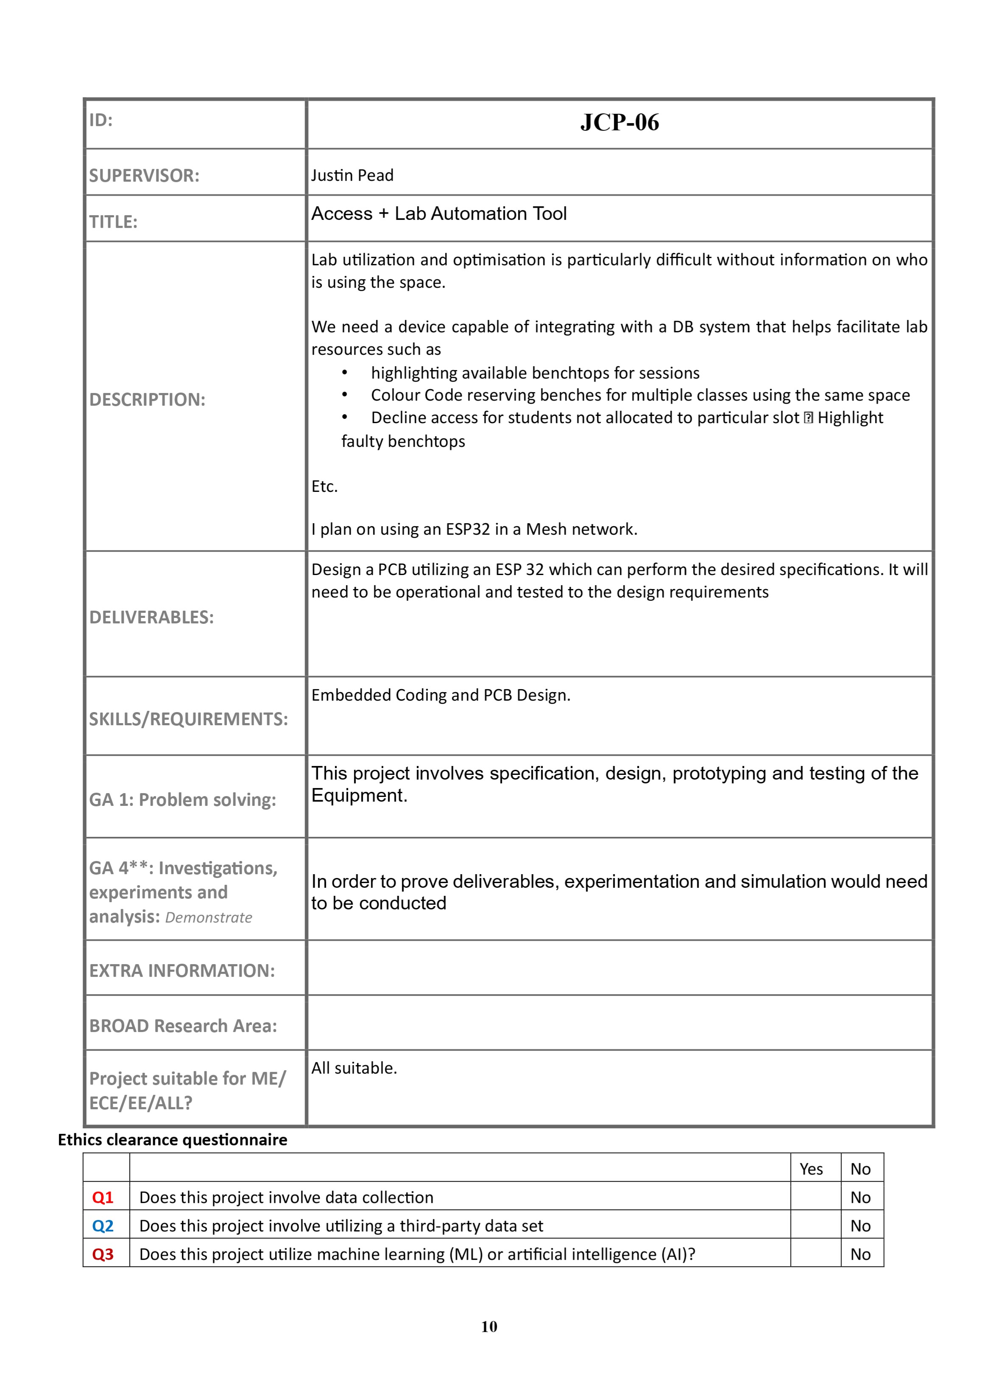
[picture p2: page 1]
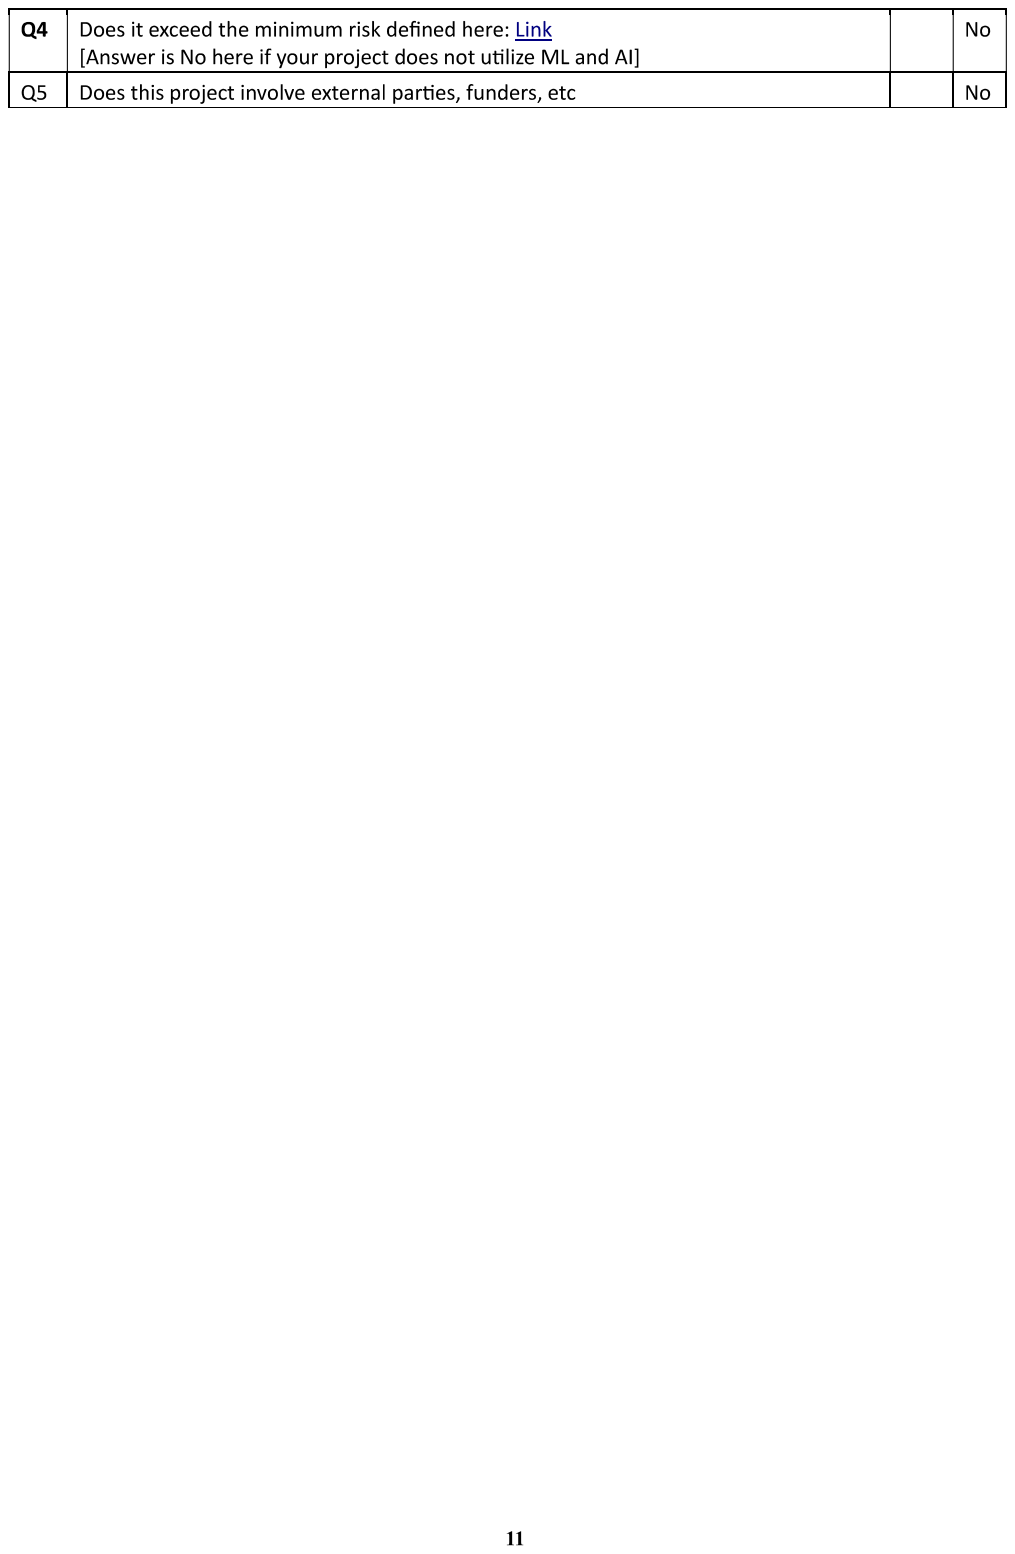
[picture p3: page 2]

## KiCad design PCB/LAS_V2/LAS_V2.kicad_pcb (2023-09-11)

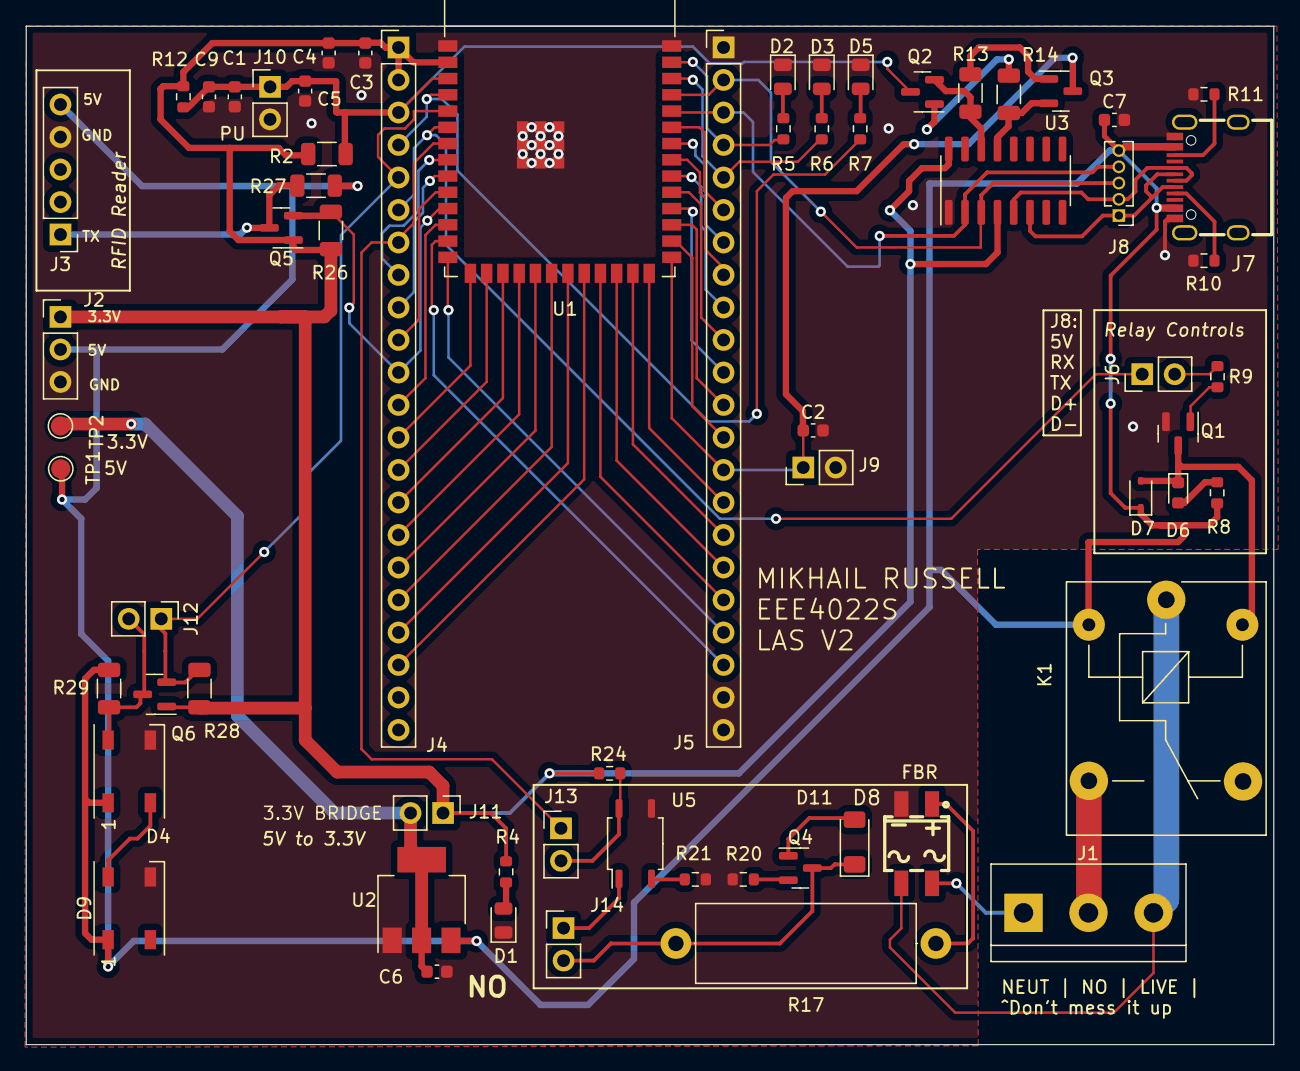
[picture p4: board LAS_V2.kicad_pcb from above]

Board: 2 copper layers, 97.5 x 79.6 mm, 65 parts (0 on the bottom side), 70 nets.

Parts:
C1: 1uF; C_0603_1608Metric
C2, C4, C5: 0.1uF; C_0603_1608Metric
C3, C6: 10uF; C_0603_1608Metric
C7, C9: 1uF/16V (10%); C_0603_1608Metric
D1, D2: RED LED; LED_0805_2012Metric
D3: YELLOW LED; LED_0805_2012Metric
D4, D9: WS2812B; LED_WS2812B_PLCC4_5.0x5.0mm_P3.2mm
D5: GREEN LED; LED_0805_2012Metric
D6: LED; LED_0603_1608Metric
D7: 1N5819WS; D_SOD-323
D8: MB10S; MBS_L4.7-W3.8-P2.40-LS7.0-TL
D11: ZMMxx; D_MiniMELF
J1: Screw_Terminal_01x03; TerminalBlock_bornier-3_P5.08mm
J2: Conn_01x03_Pin; PinHeader_1x03_P2.54mm_Vertical
J3: Conn_01x05_Socket; PinHeader_1x05_P2.54mm_Vertical
J4, J5: Conn_01x22_Socket; PinHeader_1x22_P2.54mm_Vertical
J6, J9, J10, J11, J12, J13, J14: Conn_01x02_Pin; PinHeader_1x02_P2.54mm_Vertical
J7: USB_C_Receptacle_USB2.0; USB-C_SMD-TYPE-C-31-M-12
J8: Conn_01x05; PinHeader_1x05_P1.27mm_Vertical
K1: SRD-05VDC-SL-C; Relay_SPDT_SANYOU_SRD_Series_Form_C
Q1, Q2, Q3, Q4: MMBT2222A; SOT-23
Q5, Q6: AO3400A; SOT-23
R2, R13, R14, R26, R27, R28, R29: 10k; R_1206_3216Metric
R4, R5, R6, R7, R8, R21: 1k; R_0603_1608Metric
R9: 150; R_0603_1608Metric
R10, R11: 5.1k; R_0603_1608Metric
R12: 10k (1%); R_0603_1608Metric
R17: 47k 3W; R_Axial_DIN0617_L17.0mm_D6.0mm_P20.32mm_Horizontal
R20, R24: 2.2k; R_0603_1608Metric
TP1, TP2: TestPoint; TestPoint_Pad_D1.5mm
U1: ESP32-S3-WROOM-1
U2: AMS1117-3.3; SOT-223-3_TabPin2
U3: CH340C; SOIC-16_3.9x9.9mm_P1.27mm
U5: EL357N; SOP-4_3.8x4.1mm_P2.54mm

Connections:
/+3.3V: C3.1, C4.1, J2.1, J4.1, J4.2, J11.1, Q5.1 (G), Q6.1 (G), R2.1, R4.1, R12.1, R24.2, R26.1, R28.1, U1.2 (3V3), U3.4 (V3), U3.16 (VCC)
/AC_Mon_1: J4.7, J13.1, U1.7 (GPIO7/TOUCH7/ADC1_CH6)
/BOOT_SEL: C2.1, J5.14, J9.1, Q3.3 (C), U1.27 (GPIO0/BOOT)
/CHIP_PU: C1.1, C5.1, C9.1, J4.3, J10.1, Q2.3 (C), R2.2, R12.2, U1.3 (EN)
/DIN_3.3: J4.5, J12.1, Q6.2 (S), R28.2, U1.5 (GPIO5/TOUCH5/ADC1_CH4)
/GPIO1: J5.4, R5.1, U1.39 (GPIO1/TOUCH1/ADC1_CH0)
/GPIO2: J5.5, R6.1, U1.38 (GPIO2/TOUCH2/ADC1_CH1)
/GPIO3: J4.13, U1.15 (GPIO3/TOUCH3/ADC1_CH2)
/GPIO4: J4.4, R7.1, U1.4 (GPIO4/TOUCH4/ADC1_CH3)
/GPIO6: J4.6, J6.1, U1.6 (GPIO6/TOUCH6/ADC1_CH5)
/GPIO8: J4.12, U1.12 (GPIO8/TOUCH8/ADC1_CH7/SUBSPICS1)
/GPIO9: J4.15, U1.17 (GPIO9/TOUCH9/ADC1_CH8/FSPIHD/SUBSPIHD)
/GPIO10: J4.16, U1.18 (GPIO10/TOUCH10/ADC1_CH9/FSPICS0/FSPIIO4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)
/GPIO11: J4.17, U1.19 (GPIO11/TOUCH11/ADC2_CH0/FSPID/FSPIIO5/S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)
/GPIO12: J4.18, U1.20 (GPIO12/TOUCH12/ADC2_CH1/FSPICLK/FSPIIO6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)
/GPIO13: J4.19, U1.21 (GPIO13/TOUCH13/ADC2_CH2/FSPIQ/FSPIIO7/S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)
/GPIO14: J4.20, U1.22 (GPIO14/TOUCH14/ADC2_CH3/FSPIWP/FSPIDQS/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)
/GPIO15: J4.8, U1.8 (GPIO15/U0RTS/ADC2_CH4/XTAL_32K_P)
/GPIO16: J4.9, U1.9 (GPIO16/U0CTS/ADC2_CH5/XTAL_32K_N)
/GPIO17: J4.10, U1.10 (GPIO17/U1TXD/ADC2_CH6)
/GPIO18: J4.11, Q5.2 (S), R26.2, U1.11 (GPIO18/U1RXD/ADC2_CH7/CLK_OUT3)
/GPIO19: J5.20, U1.13 (GPIO19/U1RTS/ADC2_CH8/CLK_OUT2/USB_D-)
/GPIO20: J5.19, U1.14 (GPIO20/U1CTS/ADC2_CH9/CLK_OUT1/USB_D+)
/GPIO21: J5.18, U1.23 (GPIO21)
/GPIO35: J5.13, U1.28 (SPIIO6/GPIO35/FSPID/SUBSPID)
/GPIO36: J5.12, U1.29 (SPIIO7/GPIO36/FSPICLK/SUBSPICLK)
/GPIO37: J5.11, U1.30 (SPIDQS/GPIO37/FSPIQ/SUBSPIQ)
/GPIO38: J5.10, U1.31 (GPIO38/FSPIWP/SUBSPIWP)
/GPIO39: J5.9, U1.32 (MTCK/GPIO39/CLK_OUT3/SUBSPICS1)
/GPIO40: J5.8, U1.33 (MTDO/GPIO40/CLK_OUT2)
/GPIO41: J5.7, U1.34 (MTDI/GPIO41/CLK_OUT1)
/GPIO42: J5.6, U1.35 (MTMS/GPIO42)
/GPIO45: J5.15, U1.26 (GPIO45)
/GPIO46: J4.14, U1.16 (GPIO46)
/GPIO47: J5.17, U1.24 (GPIO47/SPICLK_P/SUBSPICLK_P_DIFF)
/GPIO48: J5.16, U1.25 (GPIO48/SPICLK_N/SUBSPICLK_N_DIFF)
/LEDs/DIN: D4.4 (DIN), J12.2, Q6.3 (D), R29.2
/LIVE: D8.3, J1.3, K1.1
/N01: J1.2, K1.3
/NEUTRAL: D8.4, J1.1
/RXD0: J5.3, J8.4, U1.36 (U0RXD/GPIO44/CLK_OUT2), U3.2 (TXD)
/TXD0: J5.2, J8.3, U1.37 (U0TXD/GPIO43/CLK_OUT1), U3.3 (RXD)
/TX_RFID: J3.1, Q5.3 (D), R27.2
/USB Interface/DTR: Q3.2 (E), R14.1, U3.13 (~DTR)
/USB Interface/RTS: Q2.2 (E), R13.1, U3.14 (~RTS)
/VCC_5V: C7.1, D4.1 (VDD), D7.1 (K), D9.1 (VDD), J2.2, J3.5, J7.A4 (VBUS), J7.A9 (VBUS), J7.B4 (VBUS), J7.B9 (VBUS), J8.5, K1.2, R8.1, R27.1, R29.1, TP1.1, U2.3 (VI)
GND: C1.2, C2.2, C3.2, C4.2, C5.2, C6.2, C7.2, C9.2, D1.1 (K), D2.1 (K), D3.1 (K), D4.3 (VSS), D5.1 (K), D8.2 (-), D9.3 (VSS), J2.3, J3.4, J5.1, J5.21, J5.22, J7.A1 (GND), J7.A12 (GND), J7.B1 (GND), J7.B12 (GND), J9.2, J10.2, Q1.2 (E), R10.2, R11.2, R20.1, R21.1, U1.1 (GND), U1.40 (GND), U1.41 (GND), U2.1 (GND), U3.1 (GND), U5.3
unnamed: D1.2 (A), R4.2
unnamed: D2.2 (A), R5.2
unnamed: D3.2 (A), R6.2
unnamed: D4.2 (DOUT), D9.4 (DIN)
unnamed: D5.2 (A), R7.2
unnamed: D6.2 (A), R8.2
unnamed: D6.1 (K), D7.2 (A), K1.5, Q1.3 (C)
unnamed: D8.1 (+), R17.1
unnamed: D11.2 (A), Q4.1 (B)
unnamed: D11.1 (K), J14.2, Q4.3 (C), R17.2
unnamed: J6.2, R9.1
unnamed: J7.A5 (CC1), R10.1
unnamed: J7.B5 (CC2), R11.1
unnamed: J7.A7 (D-), J7.B7 (D-), J8.1, U3.6 (UD-)
unnamed: J7.A6 (D+), J7.B6 (D+), J8.2, U3.5 (UD+)
unnamed: C6.1, J11.2, TP2.1, U2.2 (VO)
unnamed: J13.2, R24.1, U5.4
unnamed: J14.1, U5.1
unnamed: Q1.1 (B), R9.2
unnamed: Q2.1 (B), R14.2
unnamed: Q3.1 (B), R13.2
unnamed: Q4.2 (E), R20.2
unnamed: R21.2, U5.2

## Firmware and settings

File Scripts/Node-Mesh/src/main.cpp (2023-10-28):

//************************************************************
//
//************************************************************
#include <painlessMesh.h>
#include <ArduinoJson.h>
#include <NeoPixelBus.h>
#include <WiFi.h>

#define MY_TABLE_NUM 1 // Define this units table num, Maybe need to make it ask on reset

#define   MESH_SSID       "white-lab-mesh"
#define   MESH_PASSWORD   "justinhelp"
#define   MESH_PORT       5555

#define RELAY_PIN 6

const uint16_t PixelCount = 2; 
const uint8_t PixelPin = 5; 

#define colorSaturation 128
NeoPixelBus<NeoGrbFeature, NeoWs2812xMethod> strip(PixelCount, PixelPin);
RgbColor red(colorSaturation, 0, 0);
RgbColor green(0, colorSaturation, 0);
RgbColor blue(0, 0, colorSaturation);
RgbColor white(colorSaturation);
RgbColor black(0);

HslColor hslRed(red);
HslColor hslGreen(green);
HslColor hslBlue(blue);
HslColor hslWhite(white);
HslColor hslBlack(black);


boolean active = false;

// Prototypes
void sendMessage(); 
void receivedCallback(uint32_t from, String & msg);
void newConnectionCallback(uint32_t nodeId);
void changedConnectionCallback(); 
void nodeTimeAdjustedCallback(int32_t offset); 
void delayReceivedCallback(uint32_t from, int32_t delay);

StaticJsonDocument<192> doc;
StaticJsonDocument<192> doc1;

Scheduler     userScheduler; // to control your personal task
painlessMesh  mesh;

bool calc_delay = false;
SimpleList<uint32_t> nodes;

// Task to blink the number of nodes
Task blinkNoNodes;
bool onFlag = false;

HardwareSerial RFID(1);
const int BUFFER_SIZE = 14; // RFID DATA FRAME FORMAT: 1byte head (value: 2), 10byte data (2byte version + 8byte tag), 2byte checksum, 1byte tail (value: 3)
const int DATA_SIZE = 10; // 10byte data (2byte version + 8byte tag)
const int DATA_VERSION_SIZE = 2; // 2byte version (actual meaning of these two bytes may vary)
const int DATA_TAG_SIZE = 8; // 8byte tag
const int CHECKSUM_SIZE = 2; // 2byte checksum
char tag_buffer [8];
//SoftwareSerial ssrfid = SoftwareSerial(7,8, false, 256); 

uint8_t buffer[BUFFER_SIZE]; // used to store an incoming data frame 
int buffer_index = 0;

std::array<int, 4> UpdateStatus(int status) {
    std::array<int, 4> ret;
    ret[0] = (status >> 3) & 1; // (b)
    ret[1] = (status >> 2) & 1; // (e)
    ret[2] = (status >> 1) & 1; // (r)
    ret[3] = status & 1;        // (a)
    return ret;
}

int test = 0;
// Json stuff
String incoming_string;


struct data {
  u_int8_t TABLE_NUM;
  u_int8_t STATUS;
  u_int8_t LED_colour;
};

struct Stat{
  boolean b;
  boolean e;
  boolean r;
  boolean a;
};

struct RFID_data{
  int header;
  int version;
  int token_buf[8];
  int check_sum;
  int tail;
};
RFID_data tag;

data newdata;
Stat current_stat;


void allow_access(){
  Serial.println("Allowing Access");
  strip.SetPixelColor(0, black);
  strip.Show();
  active = true;
  digitalWrite(RELAY_PIN, HIGH);
}

void deny_access(){

  strip.SetPixelColor(1, red);
  strip.Show();
  delay(200);
  strip.SetPixelColor(1, black);
  strip.Show();
  delay(200);
  strip.SetPixelColor(1, red);
  strip.Show();
  delay(200);
  strip.SetPixelColor(1, black);
  strip.Show();
  delay(200);

  digitalWrite(RELAY_PIN, LOW);

  active = false;
}

void handle_status(){
  // Now we need to manage the status
  
  if(current_stat.b == 0 && current_stat.e == 0 && current_stat.r == 0 && current_stat.a == 0){
    // Time to reset
    digitalWrite(RELAY_PIN, LOW);
    active = false;
    strip.SetPixelColor(0, green);
    strip.Show();
  }
  else{
      // First check if response flag is high
    if (current_stat.r == 1){
      // Master is responding to request, ignore rest and just accept or don't accept
      if (current_stat.a == 1){
        // Allow access:
        allow_access();

      }
      else{
        // Dont allow access:
        deny_access();
      }
    }
    else{
      // Message must be a routine status update
      if(current_stat.b and active == false){
        strip.SetPixelColor(0, blue);
        strip.Show();
      }

      if(current_stat.e){
        strip.SetPixelColor(0, green);
        strip.Show();
        delay(1000);
        strip.SetPixelColor(0, black);
        strip.Show();
        delay(1000);
        strip.SetPixelColor(0, green);
        strip.Show();
        delay(1000);
        strip.SetPixelColor(0, black);
        strip.Show();
        delay(1000);
        strip.SetPixelColor(0, green);
        strip.Show();
        delay(1000);
        strip.SetPixelColor(0, black);
        strip.Show();
      }
    }
  }
  
  
  Serial.println("Status managed");
}

void setup() {
  Serial.begin(115200);
  pinMode(RELAY_PIN, OUTPUT);
  RFID.begin(9600, SERIAL_8N1, 18, 17);

  mesh.setDebugMsgTypes(ERROR);  // set before init() so that you can see error messages

  mesh.init(MESH_SSID, MESH_PASSWORD, &userScheduler, MESH_PORT);
  mesh.onReceive(&receivedCallback);
  mesh.onNewConnection(&newConnectionCallback);
  mesh.onChangedConnections(&changedConnectionCallback);
  // mesh.onNodeTimeAdjusted(&nodeTimeAdjustedCallback);
  // mesh.onNodeDelayReceived(&delayReceivedCallback);

  strip.Begin();
  
  strip.Show();

  strip.SetPixelColor(0, red);
  strip.SetPixelColor(1, blue);
  strip.Show();
  delay(1000);
  strip.SetPixelColor(0, black);
  strip.SetPixelColor(1, black);
  strip.Show();


  Serial.println("Setup Complete!");
}

void extract_tag() {
    uint8_t msg_head = buffer[0];
    uint8_t *msg_data = buffer + 1; // 10 byte => data contains 2byte version + 8byte tag
    uint8_t *msg_data_version = msg_data;
    uint8_t *msg_data_tag = msg_data + 2;
    uint8_t *msg_checksum = buffer + 11; // 2 byte
    uint8_t msg_tail = buffer[13];

    // print message that was sent from RDM630/RDM6300
    Serial.println("--------");

    Serial.print("Message-Head: ");
    Serial.println(msg_head);

    Serial.println("Message-Data (HEX): ");
    for (int i = 0; i < DATA_VERSION_SIZE; ++i) {
      Serial.print(char(msg_data_version[i]));
  
    }
    Serial.println(" (version)");
    for (int i = 0; i < DATA_TAG_SIZE; ++i) {
      Serial.print(char(msg_data_tag[i]));
      tag_buffer[i] = msg_data_tag[i];
    }
    Serial.println(" (tag)");

    Serial.print("Message-Checksum (HEX): ");
    for (int i = 0; i < CHECKSUM_SIZE; ++i) {
      Serial.print(char(msg_checksum[i]));
    }
    Serial.println("");

    Serial.print("Message-Tail: ");
    Serial.println(msg_tail);

    Serial.println("--");
}

void loop() {
  mesh.update();

  if (RFID.available()){
    int RFID_val = RFID.read();
    if(RFID_val == -1){
      return;
    }
    Serial.println("Reading Tag");
    bool call_extract_tag = false;
    String outstr = "";
    
    u_int8_t buf[14];
    Serial.print("Start Value:");
    Serial.println(RFID_val);

    int i = 0;
    bool complete = false;
    buf[i] = RFID_val;
    while (!complete)
    {
      RFID_val = RFID.read();
      if(RFID_val == -1){
      }
      else{
        i++;
        Serial.printf("i: %i ", i);
        buf[i]= RFID_val;
        Serial.printf("buf[i]: %0x", buf[i]);
        if (buf[i] == 3){complete = true;};
      }
    }
    memcpy(&tag,&buf, 14);
    Serial.println(tag.header);
    Serial.print("tag:");
    String tagstring = "";
    for (int i = 3; i < 11; i++){
      Serial.println(buf[i]);
      tagstring = tagstring + (char)buf[i];
    }
    Serial.println(tagstring);
    doc1["t"] = MY_TABLE_NUM;
    doc1["s"] = tagstring;
    doc1["id"] = mesh.getNodeId();

    String output = ""; 
    serializeJson(doc1,output);
    mesh.sendBroadcast(output);
    int temp = 1;
    delay(100);

    while(temp != -1){
      temp = RFID.read();
    }

    //Serial.println(tag.token);
    }
  
  
    // if (ssvalue == 2) { // RDM630/RDM6300 found a tag => tag incoming 
    //   buffer_index = 0;
    // } 
    // else if (ssvalue == 3) { // tag has been fully transmitted       
    //   call_extract_tag = true; // extract tag at the end of the function call
    // }
    // buffer[buffer_index++] = ssvalue; // everything is alright => copy current value to buffer



    // if (call_extract_tag == true) {
    //   if (buffer_index == BUFFER_SIZE) {
    //     extract_tag();

    //     // Time to send tag
    //     Serial.println("Going to send:");
    //     for (int i = 0; i != 8; i++){
    //       Serial.print(tag_buffer[i]);
    //       outstr = outstr + tag_buffer[i];
    //     }

    //     doc["t"] = MY_TABLE_NUM;
    //     doc["s"] = outstr;
    //     doc["id"] = mesh.getNodeId();

    //     String output = ""; 
    //     serializeJson(doc,output);
    //     mesh.sendBroadcast(output);
    //     delay(1000);
    //     Serial.println("Clearing Buffer...");
    //     // Basically keep reading till -1 or else cards stack
    //     int temp = 1;
    //     while(temp != -1){
    //       temp = RFID.read();
    //     }
    //   } 
    //   else { // something is wrong... start again looking for preamble (value: 2)
    //     buffer_index = 0;
    //     Serial.println("Something went wrong");
    //     return;
    //   }
      
    //}
  //}

}

void receivedCallback(uint32_t from, String & msg) {
  Serial.printf("%s\n", msg.c_str());
  String modifiedMsg = msg;
  modifiedMsg.replace("'", "\"");
  DeserializationError error = deserializeJson(doc,msg.c_str());
  int t = doc["t"].as<int>(); // 1
  int s = doc["s"].as<int>(); // 12
  int time = doc["time"];
  int l = test;

  newdata.TABLE_NUM = t;
  newdata.STATUS =s;
  // if(newdata.TABLE_NUM == 0 and test != 10000){
  //   String output = "";
  //   doc["t"] = 0;
  //   doc["s"] = s;
  //   int l = test;
  //   doc["l"] = l;
  //   doc["time"] = time;

  //   serializeJson(doc, output);
  //   mesh.sendBroadcast(output);
  //   test = test+1;
  // }
  if(newdata.TABLE_NUM == MY_TABLE_NUM){
    
    std::array<int, 4> result = UpdateStatus(newdata.STATUS);
    Serial.print(result[0]); Serial.print(" ");
    Serial.print(result[1]); Serial.print(" ");
    Serial.print(result[2]); Serial.print(" ");
    Serial.print(result[3]); Serial.print(" ");

    // Update status then go manage
    current_stat.b = result[0];
    current_stat.e = result[1];
    current_stat.r = result[2];
    current_stat.a = result[3];
    handle_status();
  }
}

void newConnectionCallback(uint32_t nodeId) {
  Serial.printf("--> startHere: New Connection, nodeId = %u\n", nodeId);
  Serial.printf("--> startHere: New Connection, %s\n", mesh.subConnectionJson(true).c_str());
}

void changedConnectionCallback() {
  Serial.printf("Changed connections\n");
  // Reset blink task
  onFlag = false;
 
  nodes = mesh.getNodeList();

  Serial.printf("Num nodes: %d\n", nodes.size());
  Serial.printf("Connection list:");

  SimpleList<uint32_t>::iterator node = nodes.begin();
  while (node != nodes.end()) {
    Serial.printf(" %u", *node);
    node++;
  }
  Serial.println();
  calc_delay = true;
}

void nodeTimeAdjustedCallback(int32_t offset) {
  Serial.printf("Adjusted time %u. Offset = %d\n", mesh.getNodeTime(), offset);
}

void delayReceivedCallback(uint32_t from, int32_t delay) {
  Serial.printf("Delay to node %u is %d us\n", from, delay);
}

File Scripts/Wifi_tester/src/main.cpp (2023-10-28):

#include <Arduino.h>
#include <WiFi.h>
#include <esp_wifi.h>
#include <ArduinoJson.h>
#include <painlessMesh.h>
#include "painlessmesh/protocol.hpp"
#include "plugin/performance.hpp"

Scheduler     userScheduler; // to control your personal task
using namespace painlessmesh;
#define   MESH_SSID       "white-lab-mesh"
#define   MESH_PASSWORD   "justinhelp"
#define   MESH_PORT       5555
painlessMesh  mesh;
StaticJsonDocument<192> doc;
int test = 0;
int buf[200];
struct table_0_data{
  int table;
  int s;
  int l;
  int RSSI;
};
table_0_data data;
SimpleList<uint32_t> nodes;
uint8_t master_address[] = {0x7C,0xDF,0xA1, 0xFD,0x70,0xD4};

// typedef struct {
//     uint8_t bssid[6];                     /**< MAC address of AP */
//     uint8_t ssid[33];                     /**< SSID of AP */
//     uint8_t primary;                      /**< channel of AP */
//     wifi_second_chan_t second;            /**< secondary channel of AP */
//     int8_t  rssi;                         /**< signal strength of AP */
//     wifi_auth_mode_t authmode;            /**< authmode of AP */
//     wifi_cipher_type_t pairwise_cipher;   /**< pairwise cipher of AP */
//     wifi_cipher_type_t group_cipher;      /**< group cipher of AP */
//     wifi_ant_t ant;                       /**< antenna used to receive beacon from AP */
//     uint32_t phy_11b:1;                   /**< bit: 0 flag to identify if 11b mode is enabled or not */
//     uint32_t phy_11g:1;                   /**< bit: 1 flag to identify if 11g mode is enabled or not */
//     uint32_t phy_11n:1;                   /**< bit: 2 flag to identify if 11n mode is enabled or not */
//     uint32_t phy_lr:1;                    /**< bit: 3 flag to identify if low rate is enabled or not */
//     uint32_t wps:1;                       /**< bit: 4 flag to identify if WPS is supported or not */
//     uint32_t ftm_responder:1;             /**< bit: 5 flag to identify if FTM is supported in responder mode */
//     uint32_t ftm_initiator:1;             /**< bit: 6 flag to identify if FTM is supported in initiator mode */
//     uint32_t reserved:25;                 /**< bit: 7..31 reserved */
//     wifi_country_t country;               /**< country information of AP */
// } wifi_ap_record_t;

wifi_ap_record_t record;
typedef struct {
  unsigned frame_ctrl: 16;
  unsigned duration_id: 16;
  uint8_t addr1[6]; /* receiver address */
  uint8_t addr2[6]; /* sender address */
  uint8_t addr3[6]; /* filtering address */
  unsigned sequence_ctrl: 16;
  uint8_t addr4[6]; /* optional */
} wifi_ieee80211_mac_hdr_t;

typedef struct {
  wifi_ieee80211_mac_hdr_t hdr;
  uint8_t payload[0]; /* network data ended with 4 bytes csum (CRC32) */
} wifi_ieee80211_packet_t;

bool first = true;
void promiscuous_rx_cb(void *buf, wifi_promiscuous_pkt_type_t type) {

    // All espnow traffic uses action frames which are a subtype of the mgmnt frames so filter out everything else.
    // if (type != WIFI_PKT_MGMT)
    //   return;

    const wifi_promiscuous_pkt_t *ppkt = (wifi_promiscuous_pkt_t *)buf;
    const wifi_ieee80211_packet_t *ipkt = (wifi_ieee80211_packet_t *)ppkt->payload;
    const wifi_ieee80211_mac_hdr_t *hdr = &ipkt->hdr;
    
    int rssi = ppkt->rx_ctrl.rssi;
    uint8_t mac[6];
    memcpy(mac, hdr->addr2, 6);
    // for(int i = 0; i < 6; i++){
    //   Serial.printf("%x",mac[i]);
    //   Serial.print(",");
    // }
    if (memcmp(mac, master_address, 6) == 0) {
    data.RSSI = rssi;
    first = false;
    }
}

void OnDataRecv(const uint8_t * mac, const uint8_t *incomingData, int len) {
  memcpy(&buf, incomingData, sizeof(incomingData));
}
void receivedCallback(uint32_t from, String & msg) {
  
  Serial.printf("%s\n", msg.c_str());
  String modifiedMsg = msg;
  modifiedMsg.replace("'", "\"");
  DeserializationError error = deserializeJson(doc,msg.c_str());
  int t = doc["t"].as<int>(); // 1
  int s = doc["s"].as<int>(); // 12
  int time = doc["time"];
  int l = test;

  String output = "";
  doc["t"] = 0;
  doc["s"] = s;
  doc["l"] = l;
  doc["time"] = time;
  doc["rssi"] = data.RSSI;
  
  for(int i = 0; i<33;i++){
    char ssid_char = record.ssid[i];
    Serial.print(ssid_char);
  }
  Serial.println();

  serializeJson(doc, output);
  mesh.sendBroadcast(output);
  test = test+1;
}

void newConnectionCallback(uint32_t nodeId) {
  Serial.printf("--> startHere: New Connection, nodeId = %u\n", nodeId);
  Serial.printf("--> startHere: New Connection, %s\n", mesh.subConnectionJson(true).c_str());
}
void changedConnectionCallback() {
  Serial.printf("Changed connections\n");
  // Reset blink task
 
  nodes = mesh.getNodeList();

  Serial.printf("Num nodes: %d\n", nodes.size());
  Serial.printf("Connection list:");

  SimpleList<uint32_t>::iterator node = nodes.begin();
  while (node != nodes.end()) {
    Serial.printf(" %u", *node);
    node++;
  }
  Serial.println();
}
void setup() {
  Serial.begin(115200);

  // Set WiFi to station mode and disconnect from an AP if it was previously connected
  WiFi.mode(WIFI_STA);
  WiFi.disconnect();
  delay(100);
  mesh.setDebugMsgTypes(ERROR | DEBUG);  // set before init() so that you can see error messages
  
  mesh.init(MESH_SSID, MESH_PASSWORD, &userScheduler, MESH_PORT);
  plugin::performance::begin(mesh, 2);
  mesh.onReceive(&receivedCallback);
  mesh.onNewConnection(&newConnectionCallback);
  mesh.onChangedConnections(&changedConnectionCallback);


  esp_wifi_set_promiscuous(true);
  esp_wifi_set_promiscuous_rx_cb(&promiscuous_rx_cb);

  Serial.println("Setup done");
}

void loop() {
  mesh.update();
  esp_wifi_sta_get_ap_info(&record);
  //esp_wifi_sta_get_ap_info(&record);
  //esp_wifi_scan_get_ap_records
  // WiFi.scanNetworks will return the number of networks found
  // int n = WiFi.scanNetworks();
  // if (n == 0) {
  //     Serial.println("no networks found");
  // } else {
  //   for (int i = 0; i < n; ++i) {
  //     // Print SSID and RSSI for each network found
  //     if(WiFi.SSID(i) == "white-lab-mesh"){
  //       Serial.println(WiFi.RSSI(i));
  //     }
  //   }
  // }

  // Wait a bit before scanning again
}

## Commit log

2023-08-07 Added PCB so far, no MC support
    [LAS_V1.kicad_pcb, LAS_V1.kicad_sch]
2023-08-07 Added more relay components, LEDS, Clearing Up
    [LAS_V1.kicad_sch, LEDs.kicad_sch, Power.kicad_sch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]
2023-08-07 Touch ups
    [LAS_V1.kicad_sch, Relay_Controls.kicad_sch]
2023-08-26 installing JLB, PCB mostly done
    [AC_Monitor_sch.kicad_sch, LAS_V1.kicad_sch, LEDs.kicad_sch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]
2023-08-29 added JLBPCB part Numbers
    [AC_Monitor_sch.kicad_sch, LAS_V1.kicad_sch, LEDs.kicad_sch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]
2023-08-29 All components Placed on PCB
    [AC_Monitor_sch.kicad_sch, BOM-LAS_V1.csv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]
2023-08-29 PCB V1 complete
    [AC_Monitor_sch.kicad_sch, LAS_V1.kicad_pcb, LAS_V1.kicad_sch]
2023-08-30 PCBV1 done, moving onto V2
    [BOM-LAS_V1.csv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]
2023-08-30 Replaced components
    [AC_Monitor_sch.kicad_sch, LAS_V2.kicad_pcb, LAS_V2.kicad_sch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]
2023-09-03 Need to redo PCB again
    [AC_Monitor_sch.kicad_sch, LAS_V2.kicad_pcb, LAS_V2.kicad_sch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]
2023-09-03 Updated rme
    [LAS_V2.kicad_pcb]
2023-09-11 Final Changes to PCB, more code for gateway
    [AC_Monitor_sch.kicad_sch, BOM-LAS_V2.csv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]
2023-09-18 idk, just before swaping maybe
    [main.cpp]
2023-09-18 Swapped around espcam and S3
    [main.cpp]
2023-09-26 No clue, more gateway I think
    [Power Budget 2.xlsx, Power Budget.xlsx]
2023-09-28 testing code added
    [Data.xlsx]
2023-09-29 before testing strength
    [Data.xlsx, SC0.xlsx, scope_0.csv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]
2023-10-03 Added Data, About to start testing ESP-Now
    [Data.xlsx, PacketData.xlsx]
2023-10-05 ADded data and mesh tests
    [PacketData.xlsx]
2023-10-28 added code fixes
    [20231012-0001.csv, New Microsoft Excel Worksheet.xlsx, lm393.dsn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]
